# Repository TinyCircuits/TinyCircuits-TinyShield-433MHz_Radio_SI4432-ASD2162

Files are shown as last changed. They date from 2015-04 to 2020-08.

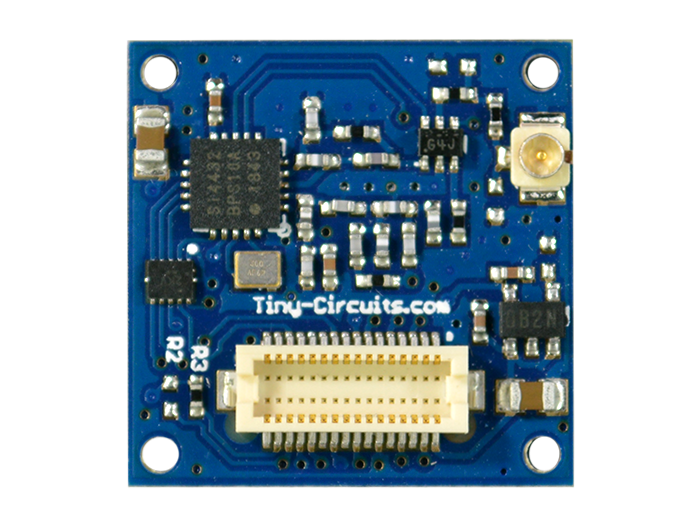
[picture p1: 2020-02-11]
images/ASD2162-R-Tutorial-Image-01.png

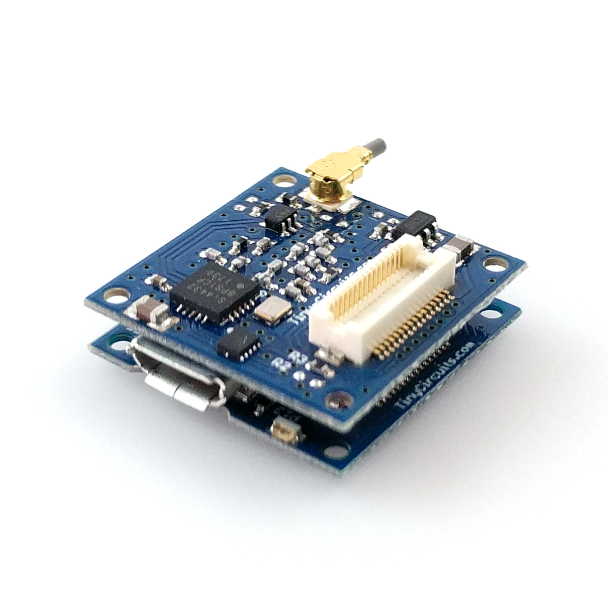
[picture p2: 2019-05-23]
images/ASD2162-R-Tutorial-Image-03.jpg

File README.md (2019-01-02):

# TinyCircuits TinyShield 433MHz radio (SI4432)
# ASD2162 Rev3

The design files are located under design-files/ for the TinyCircuits ASD2162 Rev3 PCB.  This is a TinyShield board that has a SI4432 433MHz radio transceiver and can communicate over a long distance.   

Format is in Cadsoft Eagle format - Eagle version 6.2 was used for the original design.

For more infomation on this, check out the product page at TinyCircuits.com:  https://tinycircuits.com/collections/communication/products/433mhz-long-range-radio-tinyshield

# License:

Design by TinyCircuits.
All design files are released under the Creative Commons Attribution Share-Alike 3.0 License, see the following link for details: http://creativecommons.org/licenses/by-sa/3.0

All text above must be included in any redistribution or derived design

This project uses designs and concepts developed as part of the Arduino project and the LilyPad project.  The TinyCircuits design files themselves (schematics, PCB and libraries) are not directly derived from these works' design files and have been created new, however the concepts and basic architecture behind the TinyDuino and TinyLily products are derived and we thank the hard work of the organizations below for their contributions to open-source hardware:
  
Original Arduino Uno Design by Team Arduino

LilyPad Arduino Design by Leah Buechley and Sparkfun Electronics

Please support the open-source hardware community

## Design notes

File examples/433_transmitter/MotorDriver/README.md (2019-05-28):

# TinyCircuits Dual Motor Driver Arduino Library

This library is intended for use with TinyCircuits' ASD2302 Dual Motor Driver TinyShield and ASD2303 Servo Controller Tinyshield. These shields use a ATtiny841 microcontroller with firmware that allows the 16 bit PWM outputs to be controlled through I2c. The Arduino library itself allows for easy interface using the TinyDuino platform. Included with the library is the ATtiny841 firmware- it is intended to be hackable and allow for extra functionality to be implemented(full ATtiny register access through I2C).

## Basic Example

Example programs are included that show how to drive motors or servos from the TinyDuino.

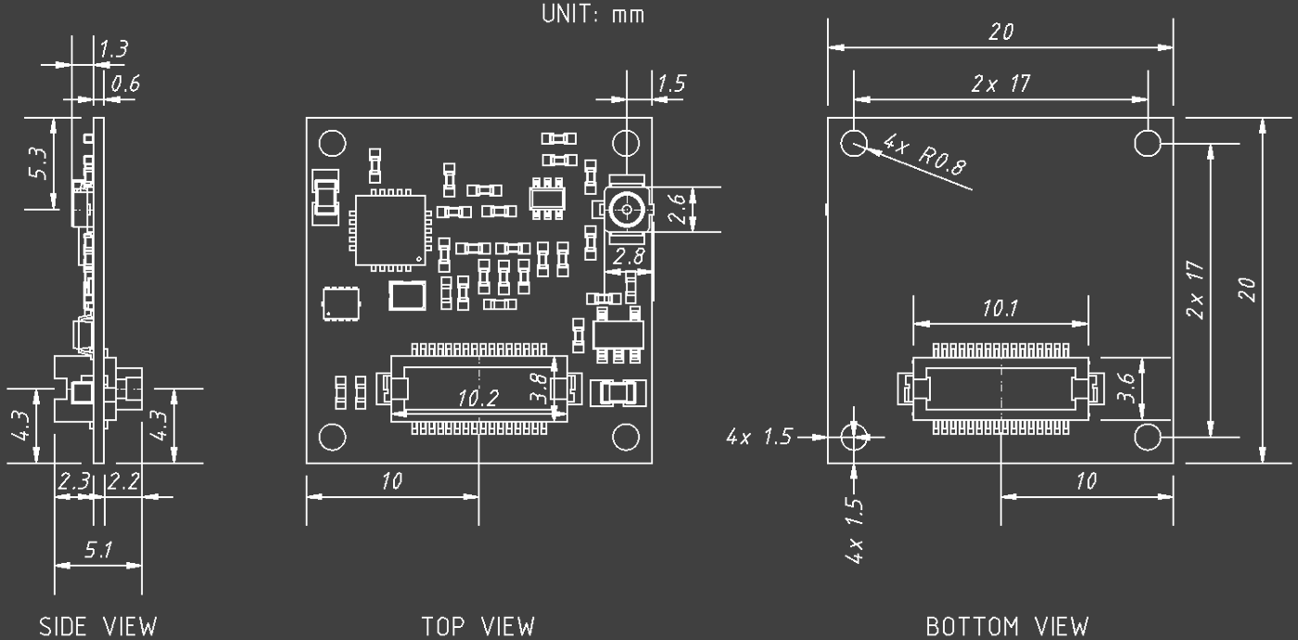
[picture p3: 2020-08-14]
cad/TinyShield_433Mhz_ASD2162_REV3-DETAILED_DRAWING_COMPACT-PNG.png

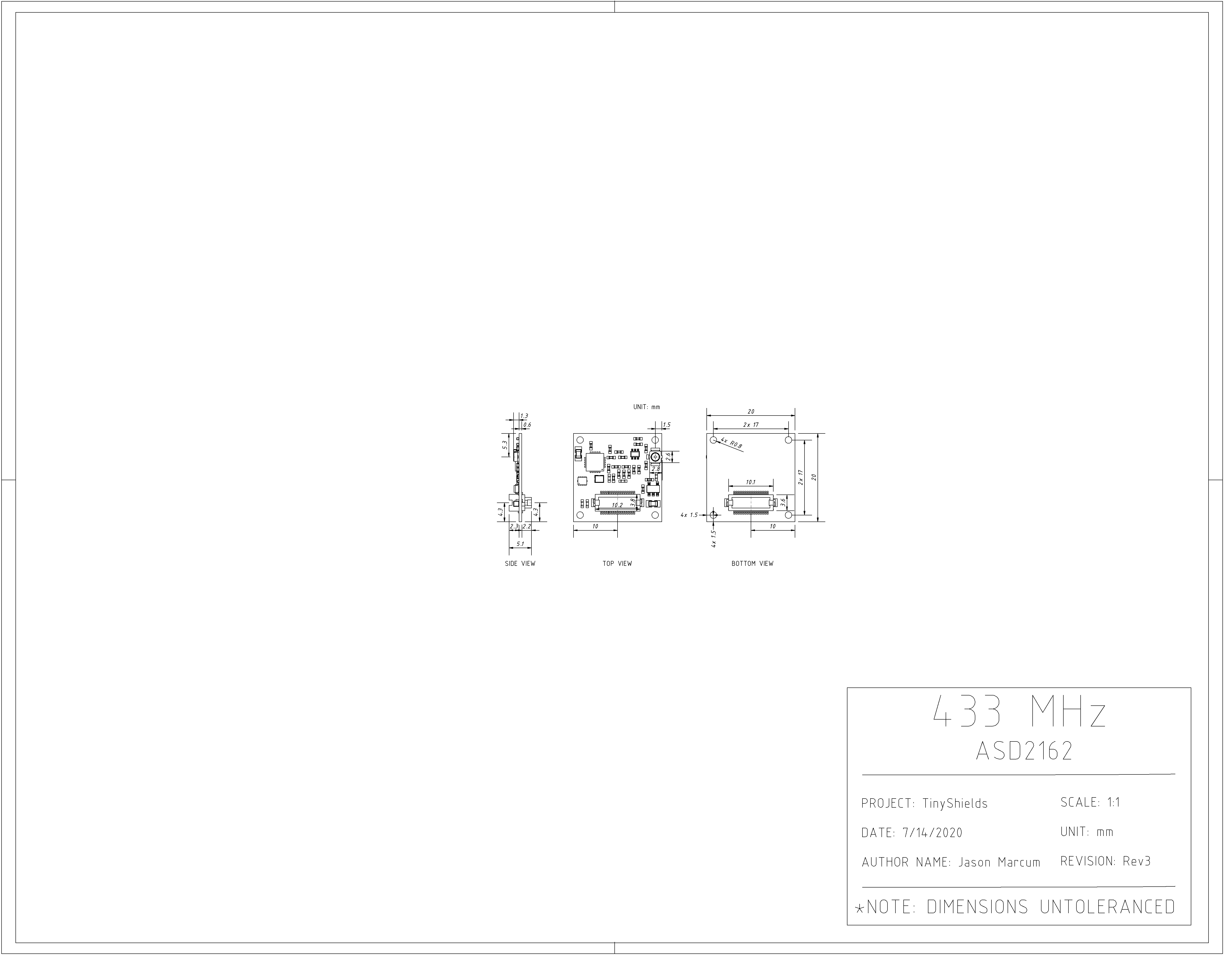
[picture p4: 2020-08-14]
cad/TinyShield_433Mhz_ASD2162_REV3-DETAILED_DRAWING-PNG.png

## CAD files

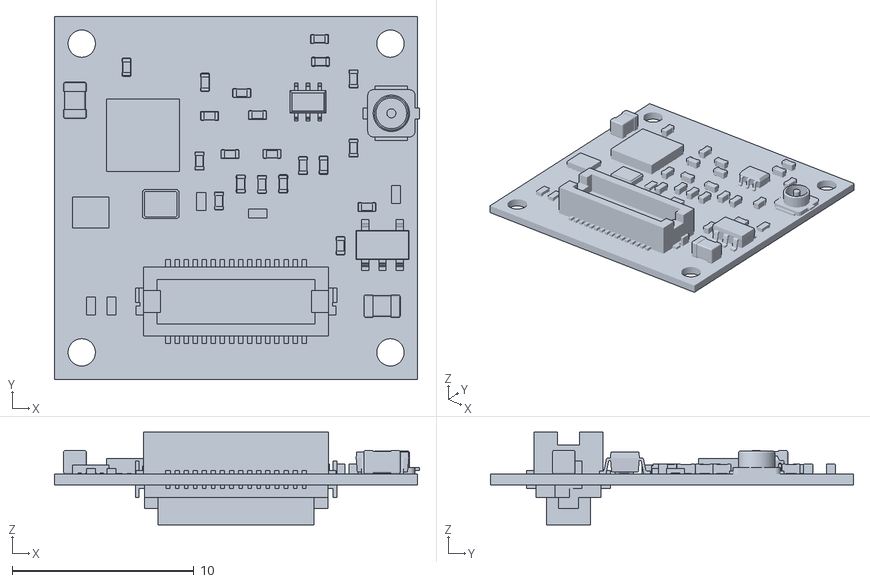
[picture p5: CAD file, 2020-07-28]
cad/TinyShield_433Mhz_ASD2162_REV3-STL.stl
20.1 x 20.0 x 5.10

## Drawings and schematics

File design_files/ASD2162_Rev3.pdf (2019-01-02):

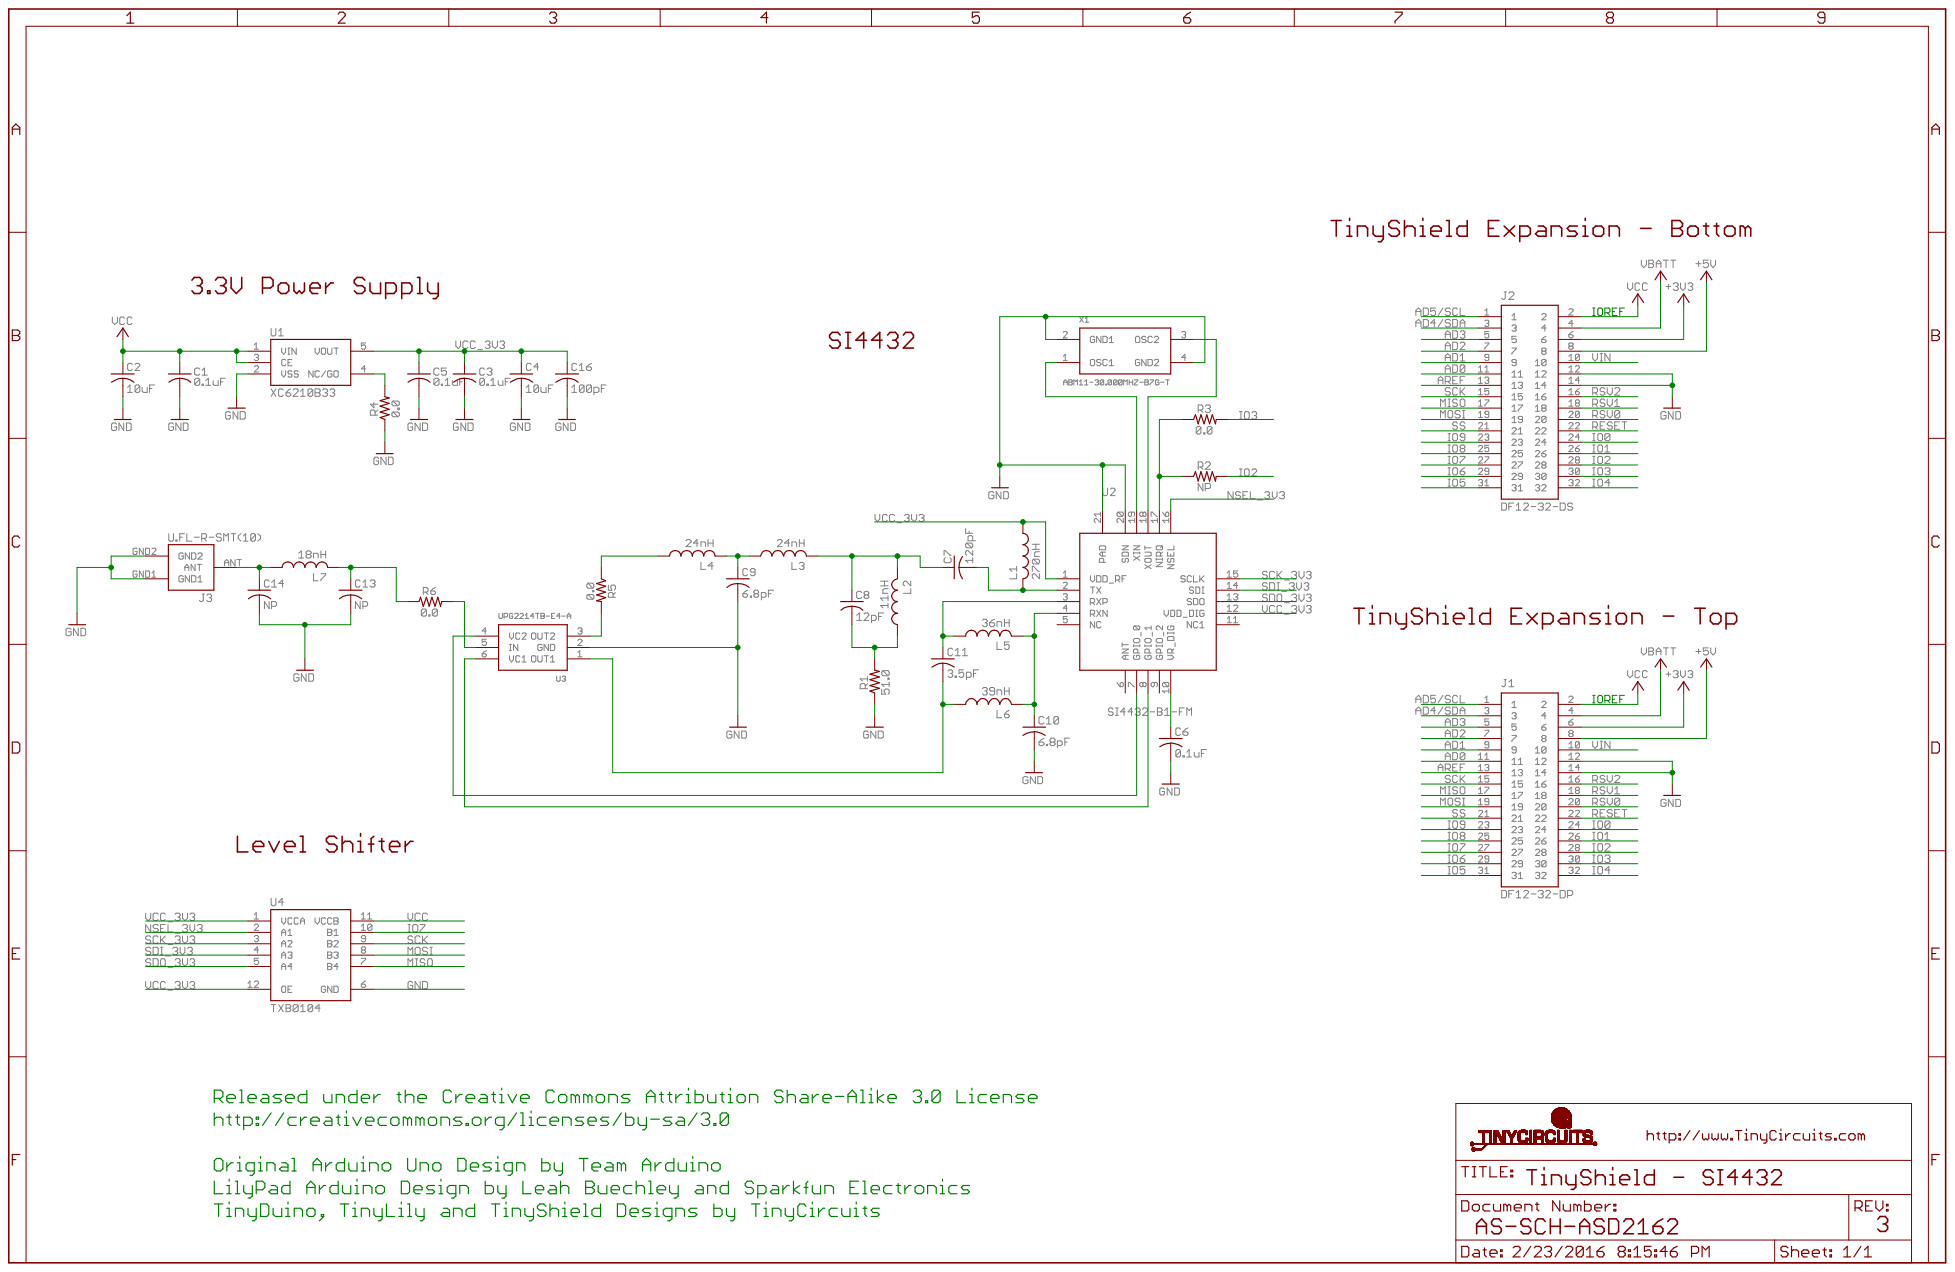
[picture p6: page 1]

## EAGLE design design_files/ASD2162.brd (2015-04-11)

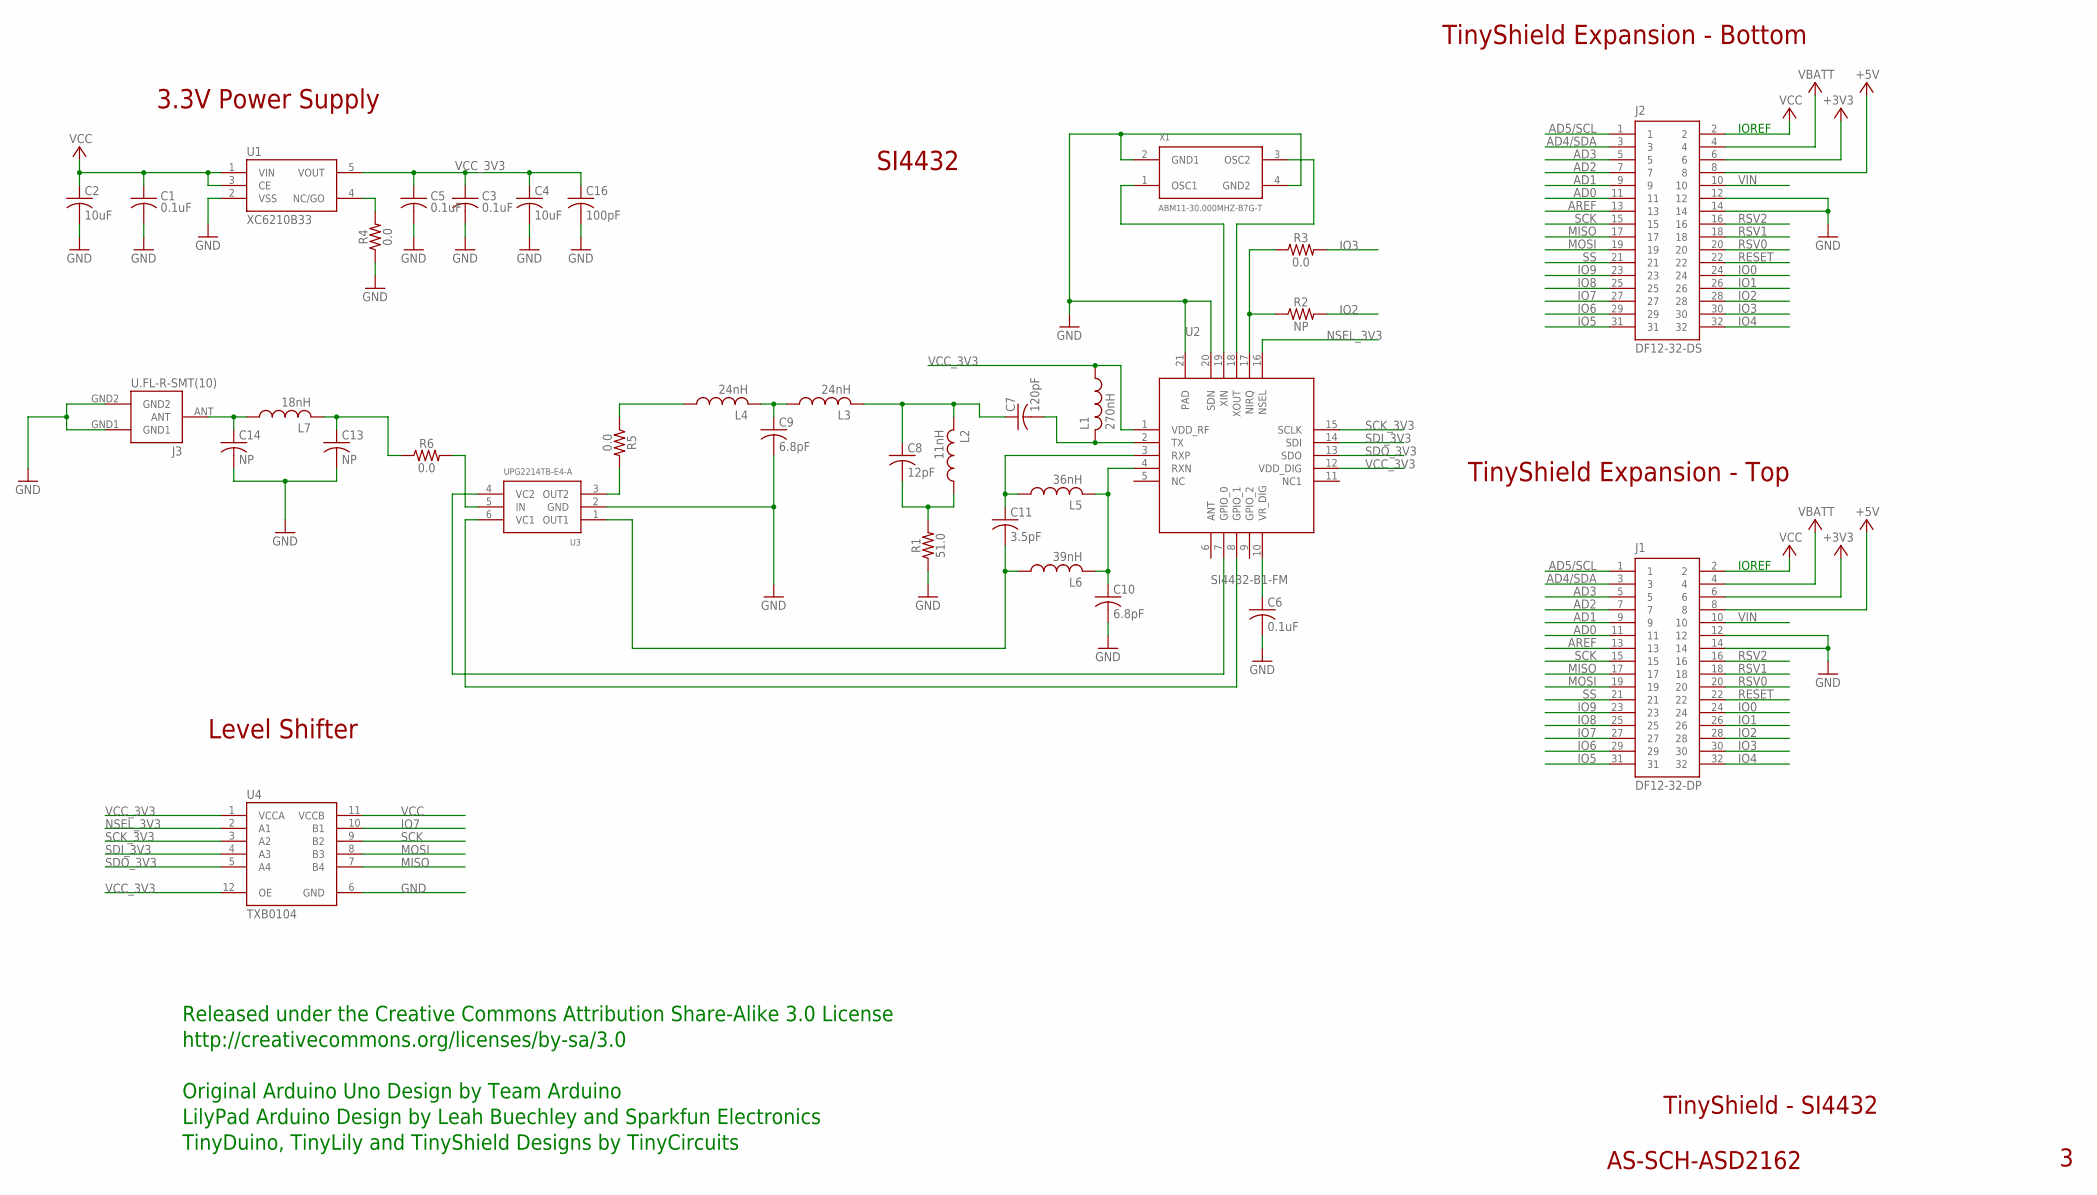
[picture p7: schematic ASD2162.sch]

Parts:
C1, C3, C5, C6: 0.1uF; C0402; PARTNO AS-ITM-00008
C2, C4: 10uF; C0805; PARTNO AS-ITM-00045
C7: 120pF; C0402
C8: 12pF; C0402; PARTNO AS-ITM-00261
C9, C10: 6.8pF; C0402; PARTNO AS-ITM-00252
C11: 3.5pF; C0402; PARTNO AS-ITM-00258
C13, C14: NP; C0402; PARTNO AS-ITM-00084
C16: 100pF; 0402
J1: DF12-32-DP; PARTNO AS-ITM-00015
J2: DF12-32-DS; PARTNO AS-ITM-00012
J3: U.FL-R-SMT(10)
L1: 270nH; C0402; PARTNO AS-ITM-00250
L2: 11nH; C0402; PARTNO AS-ITM-00254
L3, L4: 24nH; C0402; PARTNO AS-ITM-00257
L5: 36nH; C0402; PARTNO AS-ITM-00253
L6: 39nH; C0402; PARTNO AS-ITM-00259
L7: 18nH; C0402; PARTNO AS-ITM-00260
R1: 51.0; 0402; PARTNO AS-ITM-00262
R2: NP; 0402
R3, R4: 0.0; 0402
R5, R6: 0.0; C0402; PARTNO AS-ITM-00076
U1: XC6210B33; SOT-25
U2: SI4432-B1-FM; QFN20
U3: UPG2214TB-E4-A; S06
U4: TXB0104; UQFN-12
X1: ABM11-30.000MHZ-B7G-T; ABM11

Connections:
+3V3: J1.6, J2.6
+5V: J1.8, J2.8
AD0: J1.11, J2.11
AD1: J1.9, J2.9
AD2: J1.7, J2.7
AD3: J1.5, J2.5
AD4/SDA: J1.3, J2.3
AD5/SCL: J1.1, J2.1
AREF: J1.13, J2.13
GND: C1.2, C2.2, C3.2, C4.2, C5.2, C6.2, C9.2, C10.2, C13.2, C14.2, C16.2, J1.12, J1.14, J2.12, J2.14, J3.GND1, J3.GND2, R1.1, R4.1, U1.2 (VSS), U2.20 (SDN), U2.21 (PAD), U3.2 (GND), U4.6 (GND), X1.2 (GND1), X1.4 (GND2)
IO0: J1.24, J2.24
IO1: J1.26, J2.26
IO2: J1.28, J2.28, R2.2
IO3: J1.30, J2.30, R3.2
IO4: J1.32, J2.32
IO5: J1.31, J2.31
IO6: J1.29, J2.29
IO7: J1.27, J2.27, U4.10 (B1)
IO8: J1.25, J2.25
IO9: J1.23, J2.23
MISO: J1.17, J2.17, U4.7 (B4)
MOSI: J1.19, J2.19, U4.8 (B3)
unnamed: U2.19 (XIN), X1.1 (OSC1)
unnamed: U2.18 (XOUT), X1.3 (OSC2)
unnamed: C10.1, L5.2, L6.2, U2.4 (RXN)
unnamed: C7.2, L1.2, U2.2 (TX)
unnamed: C6.1, U2.10 (VR_DIG)
unnamed: C7.1, C8.1, L2.2, L3.2
unnamed: C8.2, L2.1, R1.2
unnamed: C9.1, L3.1, L4.2
unnamed: C11.1, L5.1, U2.3 (RXP)
unnamed: R5.2, U3.3 (OUT2)
unnamed: C11.2, L6.1, U3.1 (OUT1)
unnamed: U2.7 (GPIO_0), U3.4 (VC2)
unnamed: U2.8 (GPIO_1), U3.6 (VC1)
unnamed: L4.1, R5.1
unnamed: R6.2, U3.5 (IN)
unnamed: C13.1, L7.2, R6.1
unnamed: C14.1, J3.ANT, L7.1
unnamed: R2.1, R3.1, U2.17 (NIRQ)
unnamed: R4.2, U1.4 (NC/GO)
NSEL_3V3: U2.16 (NSEL), U4.2 (A1)
RESET: J1.22, J2.22
RSV0: J1.20, J2.20
RSV1: J1.18, J2.18
RSV2: J1.16, J2.16
SCK: J1.15, J2.15, U4.9 (B2)
SCK_3V3: U2.15 (SCLK), U4.3 (A2)
SDI_3V3: U2.14 (SDI), U4.4 (A3)
SDO_3V3: U2.13 (SDO), U4.5 (A4)
SS: J1.21, J2.21
VBATT: J1.4, J2.4
VCC: C1.1, C2.1, J1.2, J2.2, U1.1 (VIN), U1.3 (CE), U4.11 (VCCB)
VCC_3V3: C3.1, C4.1, C5.1, C16.1, L1.1, U1.5 (VOUT), U2.1 (VDD_RF), U2.12 (VDD_DIG), U4.1 (VCCA), U4.12 (OE)
VIN: J1.10, J2.10

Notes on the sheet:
TinyShield Expansion - Bottom
TinyShield - SI4432
AS-SCH-ASD2162
TinyShield Expansion - Top
IOREF
Released under the Creative Commons Attribution Share-Alike 3.0 License
http://creativecommons.org/licenses/by-sa/3.0
LilyPad Arduino Design by Leah Buechley and Sparkfun Electronics
TinyDuino, TinyLily and TinyShield Designs by TinyCircuits
Original Arduino Uno Design by Team Arduino
3.3V Power Supply
Level Shifter
SI4432

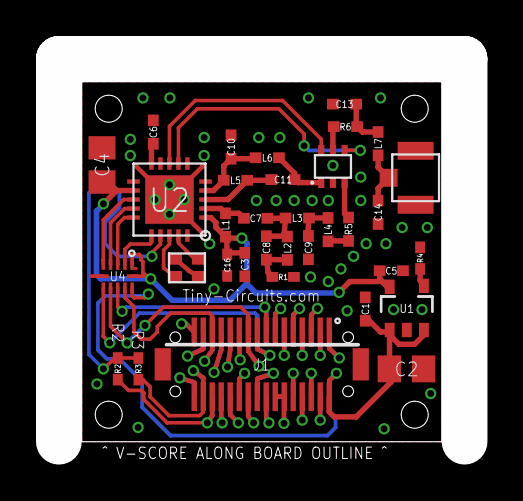
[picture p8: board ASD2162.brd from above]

Board: 2 copper layers, 20.0 x 20.0 mm, 36 parts (1 on the bottom side), 55 nets.

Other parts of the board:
U$1: DOCFIELD-TINYCIRCUITS-PCB

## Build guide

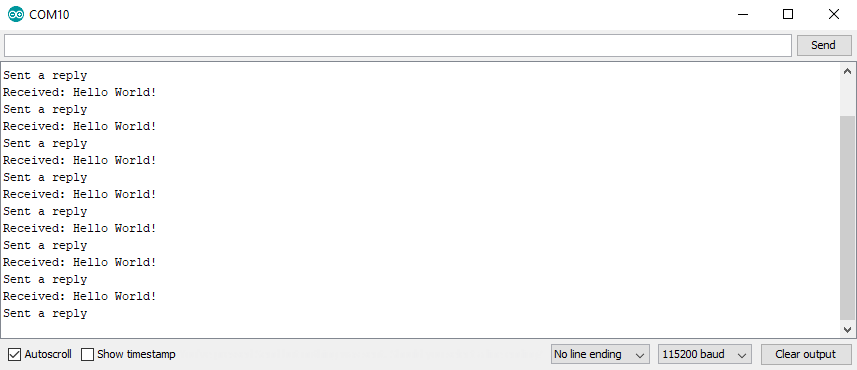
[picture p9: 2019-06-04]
images/ASD2162-R-Tutorial-Image-05.PNG

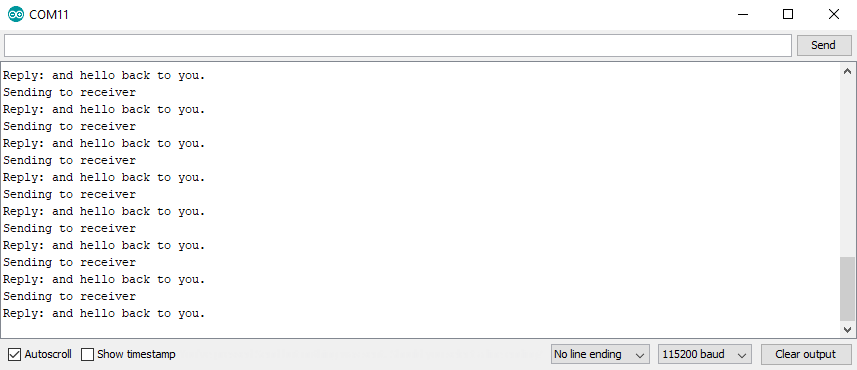
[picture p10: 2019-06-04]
images/ASD2162-R-Tutorial-Image-04.PNG

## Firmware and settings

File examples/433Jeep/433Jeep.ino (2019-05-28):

#define use433 1


#include <Wire.h>
#include <SPI.h>
#include <RH_NRF24.h>
#include <RH_RF22.h>
#include "RTIMUSettings.h"
#include "RTIMU.h"
#include "RTFusionRTQF.h"
#include "CalLib.h"

RTIMU *imu;                                           // the IMU object
RTFusionRTQF fusion;                                  // the fusion object
RTIMUSettings settings;                               // the settings object


#include <MotorDriver.h>
#include <ServoDriver.h>

MotorDriver motor(NO_R_REMOVED);
ServoDriver servo(R1_REMOVED);

#if(use433)
RH_RF22 nrf24(7, 3);
#else
RH_NRF24 nrf24(9, 7);
#endif

long timeout = 1000;
long lastcommand = 0;

int servoHold = 2000;
int servoRelease = 1000;

int maxPWM = 500;

#if defined (ARDUINO_ARCH_AVR)
#define SerialMonitorInterface Serial
#elif defined(ARDUINO_ARCH_SAMD)
#define SerialMonitorInterface SerialUSB
#endif


void setup()
{
  SerialUSB.begin(115200);
  //while (!SerialUSB);
  Wire.begin();

#if(use433)
  nrf24.init();
  nrf24.setTxPower(RH_RF22_TXPOW_20DBM);
  nrf24.setModemConfig(RH_RF22::GFSK_Rb125Fd125);//GFSK_Rb4_8Fd45?
#else
  nrf24.init();
  nrf24.setChannel(1);
  nrf24.setRF(RH_NRF24::DataRate250kbps, RH_NRF24::TransmitPower0dBm);
#endif


  if ( motor.begin(500)) {
    SerialMonitorInterface.println("Motor driver not detected!");
    //while (1);
  }
  motor.setMotor(1, 0);
  motor.setMotor(2, 0);
  if (servo.begin(20000)) {    //Set the period to 20000us or 20ms, correct for driving most servos
    SerialMonitorInterface.println("Servo driver not detected!");
    //while (1);
  }
  servo.begin(5000);
  servo.setServo(1, 1500);

  /*
    Wire.beginTransmission(0x70);
    Wire.write(0x04 + 0);
    Wire.endTransmission();
  */
  motor.setFailsafe(100);
  imu = RTIMU::createIMU(&settings);
  imu->IMUInit();
  fusion.setGyroEnable(true);
  fusion.setAccelEnable(true);
}

int currentXdata = 0;
int currentYdata = 0;

int setPoint = 512;
int in = 0;
int lastPWM = 0;

void loop()
{
  if (imu->IMURead()) {                                // get the latest data if ready yet
    fusion.newIMUData(imu->getGyro(), imu->getAccel(), imu->getCompass(), imu->getTimestamp());
    currentXdata = fusion.getFusionPose().x() * RTMATH_RAD_TO_DEGREE;
    currentYdata = -fusion.getFusionPose().y() * RTMATH_RAD_TO_DEGREE;
    //SerialUSB.print(currentXdata);
    //SerialUSB.print('\t');
    //SerialUSB.println(currentYdata);
    
  }
  if (nrf24.available())
  {
    // Should be a message for us now
    uint8_t buf[32];
    uint8_t len = sizeof(buf);
    if (nrf24.recv(buf, &len) && buf[0] == 5)
    {
      lastcommand = millis();
      int16_t LY = buf[1] << 8 | buf[2];
      int16_t RY = buf[3] << 8 | buf[4];
      int16_t LX = buf[5] << 8 | buf[6];
      int16_t RX = buf[7] << 8 | buf[8];

      if (abs(LY) < 50) {
        LY = 0;
      }
      //motor.setMotor(1, constrain(-LY, -500, 500));
      servo.setServo(1, 1500 - 75 + constrain(1.1 * -(float)RX, -600, 500));

      motor.setMotor(1, constrain(-RY, -500, 500));
      motor.setMotor(2, constrain(LY, -500, 500));


      int voltage = getVCClevel();
      uint8_t data[8];
      data[0] = 5;
      data[1] = abs(0);
      data[2] = voltage >> 8;
      data[3] = voltage;
      data[4] = currentXdata >> 8;
      data[5] = currentXdata;
      data[6] = currentYdata >> 8;
      data[7] = currentYdata;
      nrf24.send(data, 8);
      nrf24.waitPacketSent();
      nrf24.sleep();
    }
  }
  if (millis() > lastcommand + timeout) {
    //digitalWrite(13,LOW);
    motor.setMotor(1, 0);
    motor.setMotor(2, 0);
    lastcommand = millis();
  }

}

int getVCClevel() {
  //http://forum.arduino.cc/index.php?topic=133907.0
  const long InternalReferenceVoltage = 1100L;
  /*ADMUX = (0<<REFS1) | (1<<REFS0) | (0<<ADLAR) | (1<<MUX3) | (1<<MUX2) | (1<<MUX1) | (0<<MUX0);
    delay(1);
    ADCSRA |= _BV( ADSC );
    while( ( (ADCSRA & (1<<ADSC)) != 0 ) );
    int result = (((InternalReferenceVoltage * 1024L) / ADC) + 5L) / 10L;*/
  return 1;//this should be in hundredths of a volt
}

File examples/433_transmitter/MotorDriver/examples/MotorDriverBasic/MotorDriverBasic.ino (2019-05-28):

//-------------------------------------------------------------------------------
//  TinyCircuits Dual Motor Driver Basic Example
//  Last Updated 11 July 2018
//  
//  This example code shows basic usage of the ASD2302 Dual Motor Driver TinyShield.
//  The library intance is created with the hardware address of the motor driver
//  (up to 4 boards/8 motors) and then intialized with begin(maximum PWM value).
//  The Dual Motor Driver has 16 bit PWM output capability, but keep in mind the
//  output frequency is low when using a large timer value- great for some things,
//  like driving servos. To drive the motors, use setMotor(motor, value) to set
//  motor 1 or 2 to -maxPWM to +maxPWM.
//
//  The board uses the ATtiny841 microcontroller and has direct register access-
//  so just about any of the internal peripherals could be put to use.
//
//  Written by Ben Rose, TinyCircuits http://tinycircuits.com
//
//-------------------------------------------------------------------------------


#include <Wire.h>
#include <MotorDriver.h>

MotorDriver motor(NO_R_REMOVED);//this value affects the I2C address, which can be changed by
                                //removing resistors R1 or R2. Then the corresponding R1_REMOVED,
                                //R2_REMOVED, R1_R2_REMOVED can be set.
                                //Default is NO_R_REMOVED


#if defined (ARDUINO_ARCH_AVR)
#define SerialMonitorInterface Serial
#elif defined(ARDUINO_ARCH_SAMD)
#define SerialMonitorInterface SerialUSB
#endif


int maxPWM=1000;
int steps=10;
int stepSize=maxPWM/steps;

void setup(){
  SerialMonitorInterface.begin(9600);
  Wire.begin();
  while(!SerialMonitorInterface)//This will block until the Serial Monitor is opened on TinyScreen+/TinyZero platform!
  
  
  //The value passed to begin() is the maximum PWM value, which is 16 bit(up to 65535)
  //This value also determines the output frequency- by default, 1MHz divided by the maxPWM value
  if(motor.begin(maxPWM)){
    SerialMonitorInterface.println("Motor driver not detected!");
    while(1);
  }
  //The failsafe turns off motors if a command is not sent in a certain amount of time.
  //Failsafe is set in milliseconds- comment or set to 0 to disable
  motor.setFailsafe(1000);
}

void loop(){
  int i;
  for(i=-maxPWM;i<maxPWM;i+=stepSize){
    delay(10);
    motor.setMotor(1,i);
    motor.setMotor(2,i);
  }
  for(i=maxPWM;i>-maxPWM;i-=stepSize){
    delay(10);
    motor.setMotor(1,i);
    motor.setMotor(2,i);
  }
}

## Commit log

2019-01-02 update format
    [ASD2162.brd, ASD2162.sch]
2019-05-28 added examples and libraries
    [project.cfg]
2020-07-28 Add CAD data
    [TinyShield_433Mhz_ASD2162_REV3-STL.stl]
2020-08-14 Update CAD drawing
